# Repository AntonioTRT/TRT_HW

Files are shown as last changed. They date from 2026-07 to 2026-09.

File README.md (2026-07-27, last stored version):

# TRT_HW
# STM32 Modular Audio Platform

Plataforma de hardware abierta en arquitectura Tarjeta Base y Hijas (Carrier & Daughterboard) para audio digital, DSP y control.

## Especificaciones
* MCU: STM32G474RET6 (Cortex-M4 @ 170MHz)
* Aceleradores: FMAC y CORDIC
* Bus B2B: I2S, I2C, SPI, ADC, GPIO
* Alimentación: USB-C / 9V DC
* ECAD: KiCad

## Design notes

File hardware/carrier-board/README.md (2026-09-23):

# STM32G474RET6 Carrier Board — Especificación Técnica Oficial

## 1. Descripción General

La **Carrier Board STM32G474** es una plataforma de desarrollo modular de alto rendimiento basada en el microcontrolador ARM Cortex-M4F **STM32G474RET6** (LQFP-64, hasta 170 MHz con FPU y DSP). Diseñada específicamente para fabricación y ensamblaje SMT en **JLCPCB**, utiliza encapsulados estándar fáciles de inspeccionar y soldar (**0805 pasivos, SOT-23, SOD-123 y LQFP-64**).

La tarjeta se interconecta con placas hijas (*daughterboards*) a través del conector Board-to-Board principal **J2 (2x8 pines, numeración estándar 1 a 16)**, integrando buses de comunicación (SPI1, I2C1 con gestión de energía), control de potencia (driver de motor PWM con MOSFET AO3400A) e identificación de hardware digital (HWID de 4 bits).

---

## 2. Especificaciones de Hardware

### 2.1. Alimentación y Regulación
- **Entrada Principal:** +5V nominal vía puerto **USB-C (J6)**. Cuenta con resistencias de pull-down de **5.1 kΩ** en las líneas `CC1` y `CC2` para compatibilidad completa con fuentes y cables USB-C a USB-C (Power Delivery Sink 5V/3A máx).
- **Regulador LDO:** **AMS1117-3.3** en encapsulado SOT-223, entregando un riel de +3.3V regulado (hasta 800 mA de pico / 1 A máx).
- **Filtrado y Desacoplo:**
  - Capacitores cerámicos (MLCC 0805) de **10 µF** en la entrada (+5V) y salida (+3.3V) del regulador.
  - Red de desacoplo distribuida en el MCU: **100 nF** en cada par `VDD`/`VSS` adyacente a los pines, complementados por un capacitor de carga de **10 µF**.
  - **Filtro Analógico:** Perla de ferrita (**FB1**) con capacitor de **100 nF** a masa para las líneas `VDDA` y `VREF+`, aislando el dominio analógico de ruidos digitales.
  - Pin `VBAT` unificado directamente al riel de **+3.3V**.

### 2.2. Reloj, Reset y Depuración
- **Oscilador Principal (HSE):** Cristal de cuarzo pasivo de **8.000 MHz** con capacitores de carga de **22 pF** a GND en `OSC_IN` (PF0) y `OSC_OUT` (PF1).
- **Circuito de Reset (NRST):** Pulsador táctil a GND con resistencia de pull-up de **10 kΩ** a +3.3V y capacitor cerámico de **100 nF** para supresión de rebotes mecánicos y transitorios.
- **Depuración SWD:** Huella estándar **Tag-Connect TC2030-NL / TC2030** que provee:
  - `SWDIO` en **PA13**
  - `SWCLK` en **PA14**
  - `SWO` en **PB3** (Asynchronous Trace)
  - `NRST` para hardware reset por depurador
  - `+3.3V` (VTref) y `GND`

### 2.3. Periféricos e Interfaces On-Board
- **Bus I2C1 con Gestión de Energía:**
  - `PB9` (SDA) y `PB8` (SCL).
  - Resistencias de Pull-Up de **2.2 kΩ** conectadas a un nodo conmutable controlado por el pin **PC15** (`I2C_PU_EN`).
  - Permite desconectar los pull-ups para apagar el bus en modos de bajo consumo (*Sleep/Stop*).
- **Bus SPI1:**
  - `PA5` (SCK), `PA6` (MISO), `PA7` (MOSI), `PB6` (CS).
- **Driver de Motor Low-Side (PWM):**
  - MOSFET canal N **AO3400A** (30V, 5.7A, $R_{DS(on)} < 35\text{ m}\Omega$ a 3.3V $V_{GS}$) en encapsulado SOT-23.
  - Controlado desde el pin **PB4** (Timer 3, Canal 1 / `TIM3_CH1`).
  - Red de compuerta: Resistencia de gate $R_G = 100\ \Omega$ y resistencia pull-down de seguridad $R_{PD} = 10\text{ k}\Omega$ a GND.
  - Protección inductiva: Diodo Schottky Flyback **1N5819HW** (SOD-123) en antiparalelo con la carga + capacitor cerámico de **100 nF** para amortiguación de EMI.
  - Conector de salida de motor **J1** (Paso 2.54 mm): Pin 1 = `+5V`, Pin 2 = `Drain del MOSFET`.
- **LEDs de Diagnóstico:**
  - `LED_PWR` (Verde): Polarizado a +3.3V mediante resistencia de **1 kΩ** ($I_F \approx 1.3\text{ mA}$).
  - `LED_USER` (Azul): Conectado al pin **PA5** (`SPI_SCK`) mediante resistencia de **470 Ω** (emula el `LED_BUILTIN` de Arduino Pin 13).

---

## 3. Conector Board-to-Board (J2 — 2x8 Pines, Numeración Estándar 1 a 16)

El conector principal **J2** utiliza una huella estándar de doble hilera (paso 2.00 mm / 2.54 mm) con numeración numérica consecutiva (Pines 1 al 16), organizada en fila impar (señales SPI / HWID) y fila par (alimentación / I2C / GPIOs):

### 3.1. Tabla de Mapeo Definitiva para J2

| Pin Físico J2 | Fila | Etiqueta de Red | Pin STM32G474 | Funciones Nativas STM32 | Equivalente Arduino | Descripción |
| :---: | :---: | :--- | :---: | :--- | :---: | :--- |
| **Pin 1** | Impar | `SPI_CS / PWM` | **PB6** | TIM4_CH1, TIM16_CH1N, USART1_TX | D10 / PWM | Chip Select SPI o PWM auxiliar |
| **Pin 2** | Par | `GND` | — | Riel de Masa común (0V) | GND | Masa de alimentación |
| **Pin 3** | Impar | `SPI_MOSI / PWM`| **PA7** | SPI1_MOSI, TIM3_CH2, TIM1_CH1N | D11 / PWM | Datos MOSI o salida PWM |
| **Pin 4** | Par | `+5V` | — | Riel de entrada USB VBUS | 5V | Alimentación de potencia principal |
| **Pin 5** | Impar | `SPI_MISO / PWM`| **PA6** | SPI1_MISO, TIM3_CH1, TIM16_CH1, ADC2_IN3 | D12 / PWM | Datos MISO o entrada ADC / PWM |
| **Pin 6** | Par | `TRT_GPIO_1` | **PA1** | TIM2_CH2, USART2_RTS, ADC1_IN2 | D2 / A4 | GPIO / Entrada Analógica / Timer |
| **Pin 7** | Impar | `SPI_SCK / PWM` | **PA5** | SPI1_SCK, TIM2_CH1, ADC2_IN2 | D13 / SCK | Reloj SPI / LED Builtin / PWM |
| **Pin 8** | Par | `+3.3V` | — | Salida del LDO AMS1117-3.3 | 3.3V | Lógica y alimentación de sensores |
| **Pin 9** | Impar | `HWID_0` | **PC0** | ADC1_IN6, ADC2_IN6, LPTIM1_IN1 | A0 | Identificación Hardware Bit 0 (ADC/Digital) |
| **Pin 10**| Par | `TRT_GPIO_2` | **PA4** | DAC1_OUT1, SPI1_NSS, ADC2_IN1 | A5 / DAC | GPIO / Salida Analógica Pura DAC |
| **Pin 11**| Impar | `HWID_1` | **PC1** | ADC1_IN7, ADC2_IN7, LPTIM1_OUT | A1 | Identificación Hardware Bit 1 (ADC/Digital) |
| **Pin 12**| Par | `SDA` | **PB9** | I2C1_SDA, TIM4_CH4, FDCAN1_TX | D14 / SDA | Datos I2C1 (Pull-up conmutable vía PC15) |
| **Pin 13**| Impar | `HWID_2` | **PC2** | ADC1_IN8, ADC2_IN8, LPTIM1_IN2 | A2 | Identificación Hardware Bit 2 (ADC/Digital) |
| **Pin 14**| Par | `SCL` | **PB8** | I2C1_SCL, TIM4_CH3, FDCAN1_RX | D15 / SCL | Reloj I2C1 (Compartido con BOOT0) |
| **Pin 15**| Impar | `HWID_3` | **PC3** | ADC1_IN9, ADC2_IN9, LPTIM1_ETR | A3 | Identificación Hardware Bit 3 (ADC/Digital) |
| **Pin 16**| Par | `TRT_GPIO_3` | **PB0** | TIM1_CH2N, TIM3_CH3, ADC1_IN15 | D3 / PWM | GPIO / PWM auxiliar / ADC |

---

### 3.2. Distribución Física de Pines en el Header (Vista Superior)

```text
               +-------------------+
SPI_CS   (PB6) | [ 1]         [ 2] | GND
SPI_MOSI (PA7) | [ 3]         [ 4] | +5V
SPI_MISO (PA6) | [ 5]         [ 6] | TRT_GPIO_1 (PA1)
SPI_SCK  (PA5) | [ 7]         [ 8] | +3.3V
HWID_0   (PC0) | [ 9]         [10] | TRT_GPIO_2 (PA4)
HWID_1   (PC1) | [11]         [12] | SDA        (PB9)
HWID_2   (PC2) | [13]         [14] | SCL        (PB8)
HWID_3   (PC3) | [15]         [16] | TRT_GPIO_3 (PB0)
               +-------------------+
                    Conector J2
```

---

## 4. Pines Internos y Periféricos Dedicados

| Función | Pin STM32G474 | Características |
| :--- | :--- | :--- |
| **Driver Motor (GATE)** | **PB4** | TIM3_CH1 (PWM Low-Side, MOSFET AO3400A a conector J1) |
| **Habilitador Pull-Up I2C**| **PC15** | Control digital de polarización para resistencias I2C1 (Push-Pull HIGH = ON, High-Z = OFF) |
| **LED Usuario (Azul)** | **PA5** | Compartido con SPI1_SCK (R=470Ω a GND) |
| **USB D-** | **PA11** | USB 2.0 Full Speed Data - |
| **USB D+** | **PA12** | USB 2.0 Full Speed Data + |
| **SWDIO** | **PA13** | Tag-Connect Pin 4 |
| **SWCLK** | **PA14** | Tag-Connect Pin 2 |
| **SWO** | **PB3** | Tag-Connect Pin 6 (Asynchronous SWO Trace) |

---

## 5. Guía de Integración de Firmware

### 5.1. Configuración de Option Bytes para PB8 / BOOT0
El microcontrolador **STM32G474RET6** multiplexa el pin físico 60 entre `PB8` y la señal de selección de arranque `BOOT0`.
- **Problema:** De fábrica, si `nBOOT0_SEL = 1`, en cada reinicio el hardware muestrea el pin PB8. Dado que PB8 está conectado a la línea I2C `SCL` con una resistencia de pull-up, el MCU detectará un nivel alto (`BOOT0 = 1`) y entrará en el bootloader DFU de ST en lugar de ejecutar la memoria Flash.
- **Solución Obligatoria:** Configurar el registro de Option Bytes `FLASH_OPTR`:
  - `nBOOT0_SEL = 0` (Bit 27): El valor de BOOT0 es ignorado desde el pin físico PB8 y se toma del bit de software `nBOOT0`.
  - `nBOOT0 = 1` (Bit 26): En lógica invertida, un valor de `1` equivale a `BOOT0 = 0`, forzando el arranque directo desde la **Flash Principal**.

#### Configuración por Software (HAL / Firmware):
```c
void Configure_Boot_OptionBytes(void) {
    FLASH_OBProgramInitTypeDef obInit = {0};
    
    HAL_FLASH_Unlock();
    HAL_FLASH_OB_Unlock();

    HAL_FLASHEx_OBGetConfig(&obInit);
    
    // Si nBOOT0_SEL está en 1 (muestreo por pin físico PB8), cambiar a software
    if ((obInit.UserConfig & FLASH_OPTR_nBOOT0_SEL) != 0) {
        obInit.OptionType = OPTIONBYTE_USER;
        obInit.UserType   = OB_USER_nBOOT0_SEL | OB_USER_nBOOT0;
        // nBOOT0_SEL = 0 (software), nBOOT0 = 1 (arranque en Flash)
        obInit.UserConfig = OB_nBOOT0_SEL_DISABLE | OB_nBOOT0_SET;
        
        HAL_FLASHEx_OBProgram(&obInit);
        HAL_FLASH_OB_Launch(); // Aplica cambios y reinicia el MCU
    }

    HAL_FLASH_OB_Lock();
    HAL_FLASH_Lock();
}
```

---

### 5.2. Control de Pull-Ups I2C vía PC15 (`I2C_PU_EN`)
Las resistencias de 2.2 kΩ están conectadas al pin **PC15**.

> [!WARNING]
> **Regla de Oro de Firmware para PC15:**
> - Para **ACTIVAR** el bus I2C: Configurar `PC15` como **Salida Push-Pull** en nivel **ALTO** (`GPIO_PIN_SET` = 3.3V).
> - Para **DESACTIVAR** el bus I2C: Configurar `PC15` como **Entrada Flotante (High-Z / No-Pull)**.
> - **NUNCA** configurar `PC15` como salida en nivel **BAJO** (`0V`), ya que esto forzaría a masa las líneas `SDA` y `SCL` mediante 2.2 kΩ, bloqueando la comunicación y consumiendo corriente innecesaria.

#### Implementación HAL:
```c
// Activa las resistencias de pull-up (Bus I2C operativo)
void I2C_Pullups_Enable(void) {
    GPIO_InitTypeDef GPIO_InitStruct = {0};
    __HAL_RCC_GPIOC_CLK_ENABLE();

    GPIO_InitStruct.Pin = GPIO_PIN_15;
    GPIO_InitStruct.Mode = GPIO_MODE_OUTPUT_PP;
    GPIO_InitStruct.Pull = GPIO_NOPULL;
    GPIO_InitStruct.Speed = GPIO_SPEED_FREQ_LOW;
    HAL_GPIO_Init(GPIOC, &GPIO_InitStruct);

    HAL_GPIO_WritePin(GPIOC, GPIO_PIN_15, GPIO_PIN_SET); // Alimenta +3.3V al nodo
}

// Desconecta las resistencias de pull-up (Modo bajo consumo)
void I2C_Pullups_Disable(void) {
    GPIO_InitTypeDef GPIO_InitStruct = {0};
    __HAL_RCC_GPIOC_CLK_ENABLE();

    // Configurar en entrada de alta impedancia (High-Z)
    GPIO_InitStruct.Pin = GPIO_PIN_15;
    GPIO_InitStruct.Mode = GPIO_MODE_INPUT;
    GPIO_InitStruct.Pull = GPIO_NOPULL;
    HAL_GPIO_Init(GPIOC, &GPIO_InitStruct);
}
```

---

### 5.3. Control del Driver de Motor PWM (PB4 / TIM3_CH1)
El MOSFET **AO3400A** es activado directamente por lógica de 3.3V desde `PB4`.

- **Frecuencia óptima recomendada:** 10 kHz a 20 kHz.
- Reloj APB1 (`TIM3CLK`) = 170 MHz.
  - `Prescaler = 16` $\rightarrow$ Frecuencia de conteo = 10 MHz.
  - `Period (ARR) = 999` $\rightarrow$ Frecuencia PWM = 10 kHz ($10\text{ MHz} / 1000$).
  - Resolución del ciclo de trabajo: 0 a 1000 (0% a 100%).

```c
// Iniciar señal PWM
HAL_TIM_PWM_Start(&htim3, TIM_CHANNEL_1);

// Modificar velocidad del motor (0 a 1000)
void Motor_SetSpeed(uint16_t speed) {
    if (speed > 1000) speed = 1000;
    __HAL_TIM_SET_COMPARE(&htim3, TIM_CHANNEL_1, speed);
}
```

---

## 6. Checklist Crítico para el Layout de PCB (JLCPCB)

1. **Ruta de Retorno y Bucles de Potencia del Motor (J1 / AO3400A / D1):**
   - El bucle cerrado formado por `J1 Pin 1 (+5V)` $\rightarrow$ `Motor` $\rightarrow$ `J1 Pin 2` $\rightarrow$ `Diodo 1N5819HW` debe colocarse **lo más compacto posible** para minimizar la radiación EMI.
   - Pistas de potencia entre `J1`, el Drain del MOSFET y el Source a `GND` con un ancho mínimo de **1.2 mm a 1.5 mm** (o polígono de cobre).
   - Colocar el Source del MOSFET directamente a la masa general mediante múltiples vías a plano de masa para evitar ruido por rebote de masa (*ground bounce*).
2. **Ubicación de Condensadores de Desacoplo del MCU:**
   - Cada condensador de **100 nF** debe colocarse inmediatamente adyacente a su respectivo pin `VDD`, conectando primero el pad del capacitor antes de la vía hacia el plano interno.
   - La perla de ferrita `FB1` y su capacitor de 100 nF para `VDDA`/`VREF+` deben ubicarse pegados a los pines 18 y 19.
3. **Oscilador de Cristal HSE de 8 MHz (PF0 / PF1):**
   - Trazar pistas cortas y simétricas entre el cristal y los pines del MCU.
   - Colocar un anillo de guarda de masa (`GND guard ring`) alrededor del cristal y sus capacitores de 22 pF.
   - No rutear señales digitales de alta velocidad (como PWM o SPI) por debajo del oscilador.
4. **Par Diferencial USB (PA11 / PA12):**
   - Impedancia diferencial de **90 Ω**. Ruteo en paralelo con separación constante y longitudes simétricas acopladas.
   - Mantener el plano de masa continuo por debajo sin cortes.

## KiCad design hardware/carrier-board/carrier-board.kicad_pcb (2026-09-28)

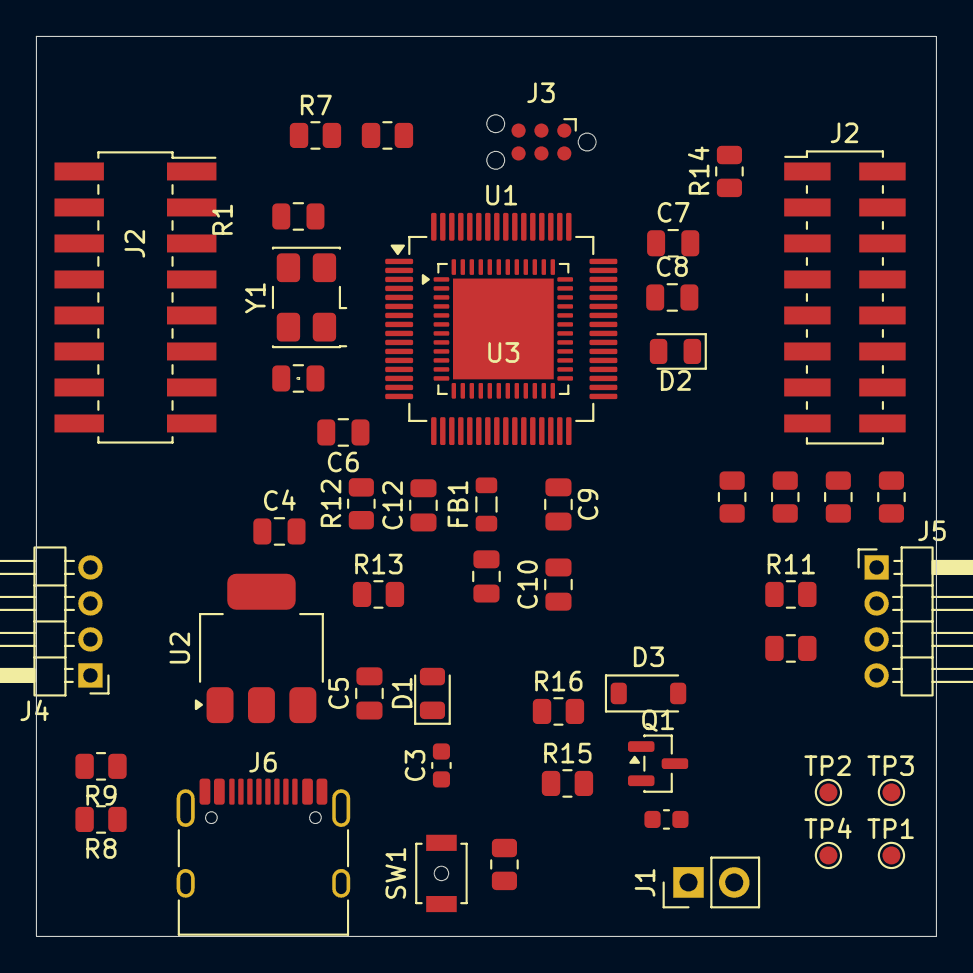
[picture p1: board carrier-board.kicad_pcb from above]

Board: 4 copper layers, 50.0 x 50.0 mm, 50 parts (0 on the bottom side), 35 nets, no tracks yet.

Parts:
C1, C2: 22pf; C_0805_2012Metric
C3, C13: 100nf; C_0603_1608Metric
C4, C5, C10: 10uF; C_0805_2012Metric
C6, C7, C8, C9, C11, C12: 100nF; C_0805_2012Metric
D1, D2: LED; LED_0805_2012Metric
D3: 1N5819HW; D_SOD-123
FB1: FerriteBead; L_0805_2012Metric
J1: Conn_01x02_Pin; PinHeader_1x02_P2.54mm_Vertical
J2: DIN41612_02x08_AB_EvenPins; PinSocket_2x08_P2.00mm_Vertical_SMD
J2#2: DIN41612_02x08_AB_EvenPins; PinHeader_2x08_P2.00mm_Vertical_SMD
J3: TC2030; Tag-Connect_TC2030-IDC-NL_2x03_P1.27mm_Vertical
J4: Conn_01x04_Socket; PinHeader_1x04_P2.00mm_Horizontal
J5: Conn_01x04_Pin; PinHeader_1x04_P2.00mm_Horizontal
J6: USB_C_Receptacle_USB2.0_16P; USB_C_Receptacle_HRO_TYPE-C-31-M-12
Q1: AO3400A; SOT-23
R1, R2, R3, R4, R5, R6, R7, R12, R15: 10k; R_0805_2012Metric
R8, R9: 5.1k; R_0805_2012Metric
R10, R11: 2.2K; R_0805_2012Metric
R13: 1k; R_0805_2012Metric
R14: 470; R_0805_2012Metric
R16: 100; R_0805_2012Metric
SW1: SW_Push; SW_SPST_B3U-1000P-B
TP1, TP2, TP3, TP4: TestPoint; TestPoint_Pad_D1.0mm
U1: STM32G474RETx; LQFP-64_10x10mm_P0.5mm
U2: AMS1117-3.3; SOT-223-3_TabPin2
U3: STM32F411CEUx; QFN-48-1EP_7x7mm_P0.5mm_EP5.6x5.6mm
Y1: Crystal_GND3; Crystal_SMD_5032-4Pin_5.0x3.2mm

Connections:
+3.3V: C4.1, C6.1, C7.1, C8.1, C9.1, C10.1, FB1.1, J2#2.8, J3.1, R1.1, R7.1, R13.1, TP1.1 (1_1), TP3.1 (1_1), U1.1 (VBAT), U1.16 (VDD), U1.28 (VREF+), U1.32 (VDD), U1.48 (VDD), U1.64 (VDD), U2.2 (VO)
+5V: C5.1, C13.1, D3.1 (K), D3.2 (A), J1.1, J1.2, J2#2.4, J4.1, J5.1, J6.A4 (VBUS), J6.A9 (VBUS), J6.B4 (VBUS), J6.B9 (VBUS), Q1.3 (D), TP2.1 (1_1), U2.3 (VI)
/mcu_core/HWID_0: J2#2.9, R2.1, U1.8 (PC0)
/mcu_core/HWID_1: J2#2.11, R3.1, U1.9 (PC1)
/mcu_core/HWID_2: J2#2.13, R4.1, U1.10 (PC2)
/mcu_core/HWID_3: J2#2.15, R5.1, U1.11 (PC3)
/mcu_core/HWID_A: R6.1, R7.2, U1.12 (PA0)
/mcu_core/I2C_PU_EN: R10.1, R11.1, U1.4 (PC15)
/mcu_core/RESET: C3.1, J3.3, R1.2, SW1.2
/mcu_core/SCL: J2#2.14, J4.3, J5.3, R10.2, U1.61 (PB8)
/mcu_core/SDA: J2#2.12, J4.2, J5.2, R11.2, U1.62 (PB9)
/mcu_core/SPI_CS / PWM: J2#2.1, U1.59 (PB6)
/mcu_core/SPI_MISO / PWM: J2#2.5, U1.20 (PA6)
/mcu_core/SPI_MOSI / PWM: J2#2.3, U1.21 (PA7)
/mcu_core/SPI_SCK / PWM: J2#2.7, R14.1, U1.19 (PA5)
/mcu_core/TRT_GPIO_1: J2#2.6, U1.13 (PA1)
/mcu_core/TRT_GPIO_2: J2#2.10, U1.18 (PA4)
/mcu_core/TRT_GPIO_3: J2#2.16, U1.24 (PB0)
/mcu_core/USB_D+: J6.B6 (D+), U1.46 (PA12)
/mcu_core/USB_D-: J6.B7 (D-), U1.45 (PA11)
/mcu_core/Vm_out: R16.1, U1.57 (PB4)
GND: C1.2, C2.2, C3.2, C4.2, C5.2, C6.2, C7.2, C8.2, C9.2, C10.2, C11.1, C12.1, C13.2, D1.1 (K), D2.1 (K), J2#2.2, J3.5, J4.4, J5.4, J6.A1 (GND), J6.A12 (GND), J6.B1 (GND), J6.B12 (GND), J6.SH (SHIELD), Q1.2 (S), R2.2, R3.2, R4.2, R5.2, R6.2, R8.2, R9.2, R12.1, R15.2, SW1.1, U1.15 (VSS), U1.27 (VSSA), U1.31 (VSS), U1.47 (VSS), U1.63 (VSS), U2.1 (GND), Y1.3
unnamed: D1.2 (A), R13.2
unnamed: D2.2 (A), R14.2
unnamed: J6.A5 (CC1), R8.1
unnamed: J6.B5 (CC2), R9.1
unnamed: Q1.1 (G), R15.1, R16.2
unnamed: J3.2, U1.49 (PA13)
unnamed: J3.4, U1.50 (PA14)
unnamed: J3.6, U1.56 (PB3)
unnamed: R12.2, U1.60 (PB7)
unnamed: C1.1, U1.5 (PF0), Y1.2
unnamed: C2.1, U1.6 (PF1), Y1.1
unnamed: C11.2, C12.2, FB1.2, TP4.1 (1_1), U1.29 (VDDA)
unnamed: U3.23 (VSS), U3.35 (VSS), U3.47 (VSS), U3.49 (VSS)

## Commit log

2026-07-27 Update README with project details
    Added project description and specifications for STM32 Modular Audio Platform.
2026-07-27 feat: Initialize KiCad base project for Carrier Board
    Adds the foundational KiCad 8 project for the Carrier Board.
    The project includes:
    - init_kicad_base.py script for automated project setup.
    - carrier-board.kicad_pro and carrier-board.kicad_sch files within hardware/carrier-board/.
    - Schematic pre-populated with essential components (MCU, USB-C, LDO, SWD, B2B, ESD) including LCSC part numbers and a configured title block.
    [carrier-board.kicad_sch]
2026-09-17 inicial schematic
    [carrier-board.kicad_pcb, carrier-board.kicad_sch, expansion.kicad_sch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]
2026-09-20 sch review
    [carrier-board.kicad_pcb, mcu_core.kicad_sch]
2026-09-23 feat(hardware): finalize schematic, update README and set initial PCB layout
    [carrier-board.kicad_pcb, mcu_core.kicad_sch]
2026-09-28 pcb placement
    [carrier-board.kicad_pcb, mcu_core.kicad_sch, peripherals.kicad_sch]
2026-11-01 daugter board
